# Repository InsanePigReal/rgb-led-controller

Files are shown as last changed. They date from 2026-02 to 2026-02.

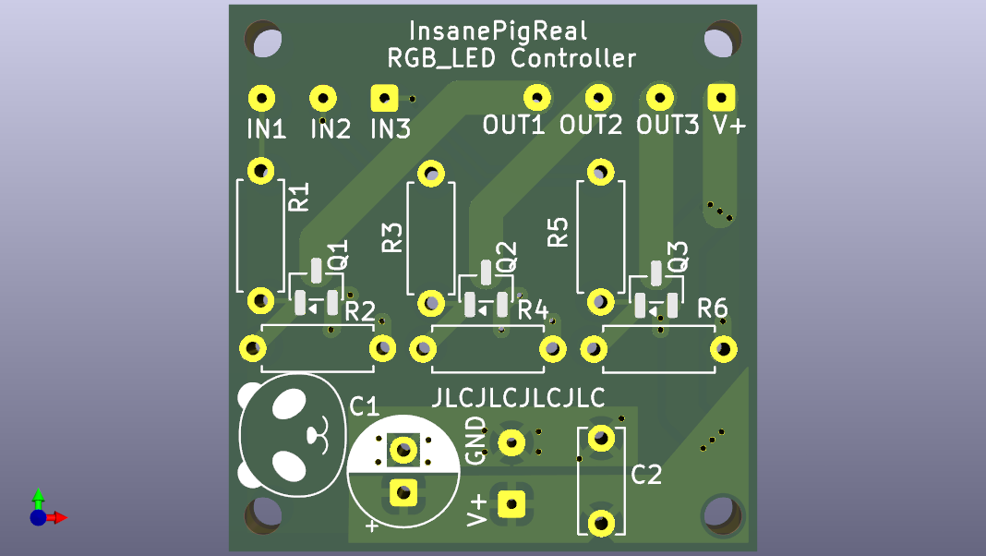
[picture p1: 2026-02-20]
assets/PCB_V5_Render.png

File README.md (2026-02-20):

# rgb-led-controller

# High-Current RGB LED Controller (24V)

A compact (30.99 mm* 32.07 mm = <1000mm^2), high efficiency PWM controller designed to drive 24V RGB LED strips using logic-level mosfets.

## Aims

- Design a small controller for an LED strip so that I can control LEDs in my house without a large, bulky controller -> the PCB must also be able to be easily mounted.
    - Previously, I controlled LEDs using components on a perfboard, however that was difficult to mount and organise with the amount of cables.
- The components must be cheap, as controllers can be purchased online for £10.
- Must functon at 24v, as the LEDs I have work at 24v.

## Specifications
- Input -> 24V - (IRLML6344 functions up to 30v)
- Control Logic -> 3.3v or 5v (micocontroller compatible) - (IRLML6344 functions up to 12v)
- Max Current -> 4A (per channel) - (limited by IRLML6344 Ip)
- Switching Frequency -> Tested up to 20kHz PWM

## Design Justification
- Trace widths:
    - Main power rails utilize 2mm traces. Based on IPC-2221 standards, this means that the traces can handle the max current of 4A.
    - Signal traces utilised 0.3mm traces, as they will not be carrying significant current (only control mosfet gates)

- Component selection:
    - IRLML6344
        - low gate threshold voltage - Vgs(th) - (0.5-1.1v), allowing it be driven with a 3.3v micocontroller signal without needing a gate driver.
        - Rated for Vds = 30v, providing a safe margin for 24v LEDs
        - Low on-resitance - Rds(on) = 29-37mΩ - minimises power dissipation, keeping the SOT-23 package cool when driving several amps of current
    - A mosfet was chosen instead of a relay due to its faster switching potential
        - This is useful for turning RGB LED strips on/off quickly -> for example, for decoration, where a mosfet will appear more seamless
        - Mosfets additonally consume less power, which is useful as the LED strips will be turned on for a large portion of the time (such as when the user is at work)
        - Mosfets are additionally more compact, which fufills one of the aims of the project (a compact RGB LED Controller
    - 100R Gate Resistor
        - Protects MCU GPIO by limiting peak current to (3.3V/100Ω=33mA)
    - 100K Pull-Down Resistor
        - Prevent floating GPIOs from causing the LEDs to flicker
        - 100K was chosen as a "weak" pull-down -> strong enough to bleed off charge but high enough to not wase significant power during operation
    - 100uF bulk electrolytic capacitor
        - Rated for 25V to ensure it can handle 24V load
        - Prevent voltage dips when switching
    - 100nF decoupling ceramic capacitor
        - Filter out high frequency noise from PWM switching -> ensures LED doesn't flicker

- Thermal managment: Added a large ground pour on the bottom layer, which will act as a heatsink for the SOT-23 mosfets.
    - SOT-23 Package can dissipate ≈ 1.25W
        - At 2A load, P = 2^2 * 0.037 = 0.148W -> design operates at a 8x safety factor regarding thermals
        - At 4A load, P = 4^2 * 0.037 = 0.592W -> design operates at a 2x safety factor regarding thermals

## Iteration and Improvements
PCB V1

1st version was not compact, meaning that it would not fit in tight spaces like I desired, as well as it being difficult to mount. Additionally, the capacitors were too far from the power supply, which would have lead to less stability and performance. Additionally, the length of the traces meant higher resistance and less signal integrity. Also, this design has no power input and no vias, so it would not have been functional.

PCB V2

2nd version improved on capacitor placement, as well as trace length and overall size. Additionally, it now included power input. However, some of the traces (such as the signal traces) were 90 degrees, which would be bad for manufacturability and signal integrity. Additionally, though I included vias, they would not be able to manufactured due to improper sizing.
Issues include the lack of moutning holes, as well as not using a ground pour and using a lot of ground traces, which created a higher impedance path. Additionally, a solid fill was used on the 24v plane, which would have made the PCB more difficult to hand solder.

PCB V5

Final version added mounting holes for the PCB, making it a more user-friendly design. Additionally, a ground pour was used instead of a the 'spider' of ground traces, and a thermal relief fill was used to make hand-soldering easier. Fixed the traces that were 90 degrees - now all traces are 45 degrees max. Furthermore, I changed the via diameter and hole size so that it fits with the chosen manufactuer's specifications. More vias were used than previously to ensure minimal voltage loss based on current.

# License
This project is licensed under the MIT License - see the LICENSE file for details

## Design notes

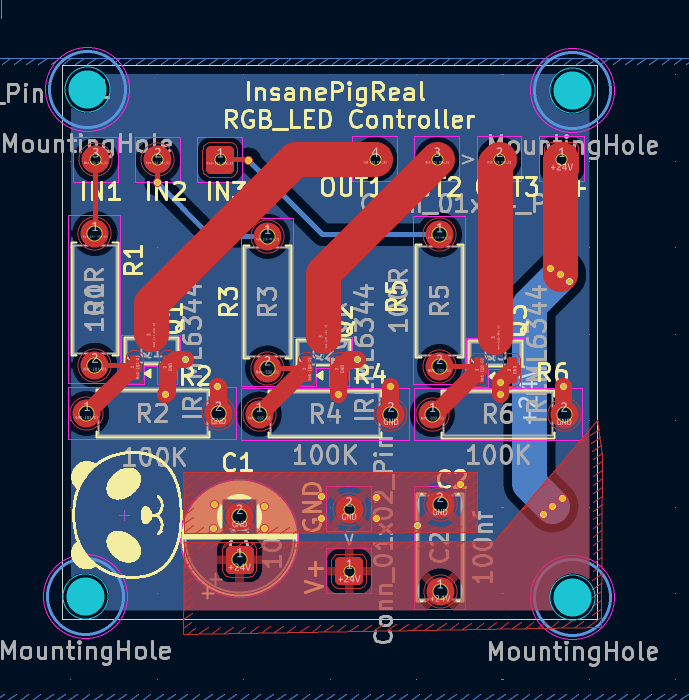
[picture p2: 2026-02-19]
assets/PCB V5.png

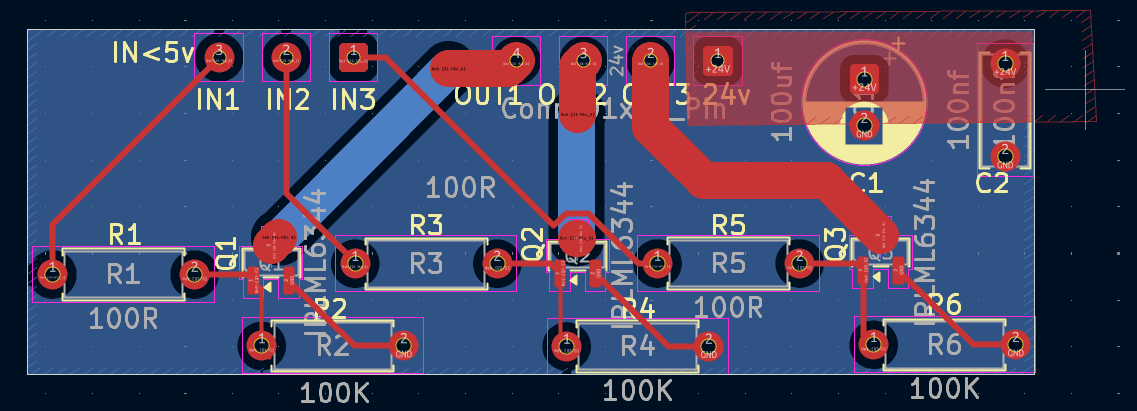
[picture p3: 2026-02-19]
assets/PCB V1.png

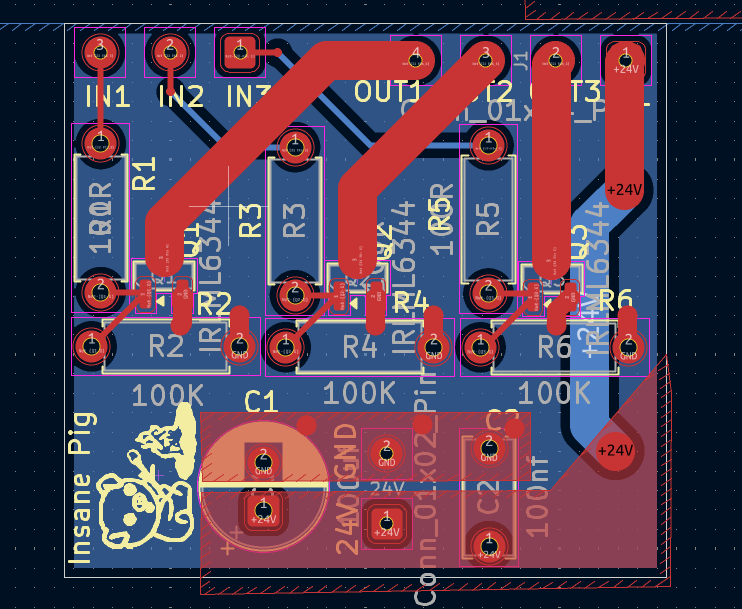
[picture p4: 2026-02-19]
assets/PCB V3.png

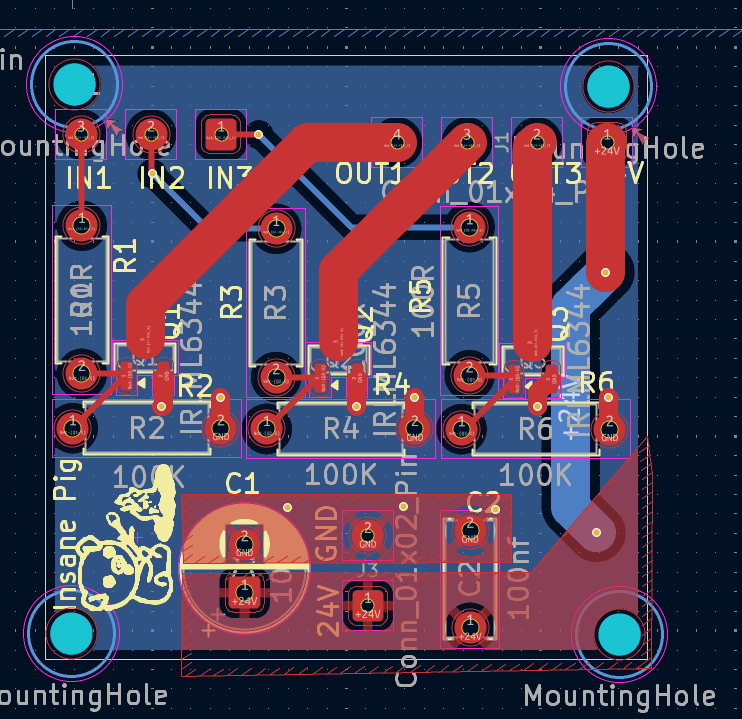
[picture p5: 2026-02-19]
assets/PCB V4.png

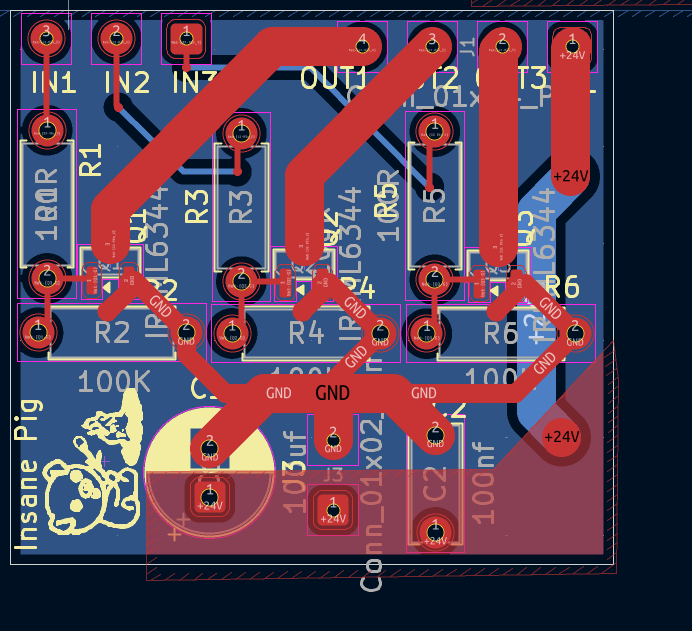
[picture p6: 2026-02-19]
assets/PCB V2.png

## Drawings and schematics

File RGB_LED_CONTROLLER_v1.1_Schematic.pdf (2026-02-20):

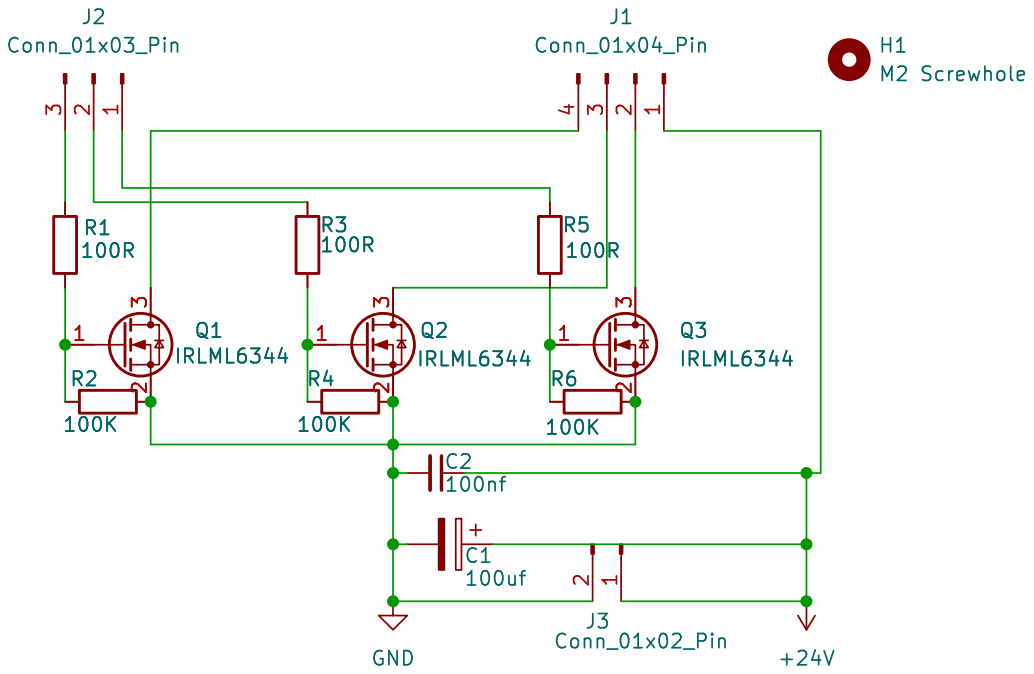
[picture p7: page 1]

Id: 1/1 Title: File: LedController1.kicad_sch Sheet: /

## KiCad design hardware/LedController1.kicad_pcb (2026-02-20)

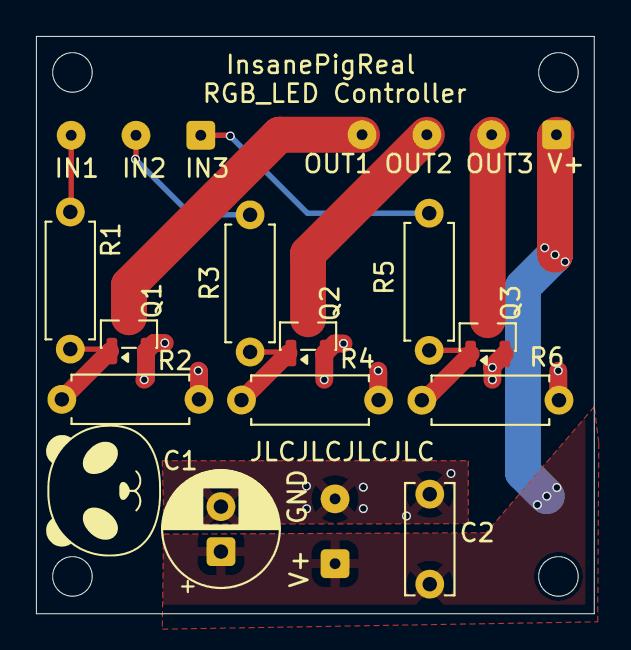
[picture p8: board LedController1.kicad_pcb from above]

Board: 2 copper layers, 31.0 x 32.1 mm, 18 parts (0 on the bottom side), 11 nets.

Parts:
C1: 100uf; CP_Radial_D6.3mm_P2.50mm
C2: 100nf; C_Disc_D6.0mm_W2.5mm_P5.00mm
H1, H1#2, H1#3, H1#4: MountingHole; MountingHole_2.2mm_M2
J2: Conn_01x03_Pin; SolderWire-0.1sqmm_1x03_P3.6mm_D0.4mm_OD1mm
Q1, Q2, Q3: IRLML6344; SOT-23
R1, R3, R5: 100R; R_Axial_DIN0207_L6.3mm_D2.5mm_P7.62mm_Horizontal
R2, R4, R6: 100K; R_Axial_DIN0207_L6.3mm_D2.5mm_P7.62mm_Horizontal
V+: Conn_01x02_Pin; SolderWire-0.1sqmm_1x02_P3.6mm_D0.4mm_OD1mm
V+#2: Conn_01x04_Pin; SolderWire-0.1sqmm_1x04_P3.6mm_D0.4mm_OD1mm

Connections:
+24V: C1.1, C2.1, V+.1, V+#2.1
GND: C1.2, C2.2, Q1.2 (S), Q2.2 (S), Q3.2 (S), R2.2, R4.2, R6.2, V+.2
unnamed: Q3.3 (D), V+#2.2
unnamed: Q2.3 (D), V+#2.3
unnamed: Q1.3 (D), V+#2.4
unnamed: J2.1, R5.1
unnamed: J2.2, R3.1
unnamed: J2.3, R1.1
unnamed: Q1.1 (G), R1.2, R2.1
unnamed: Q2.1 (G), R3.2, R4.1
unnamed: Q3.1 (G), R5.2, R6.1

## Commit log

2026-02-19 Added Kicad project files
    [LedController1.kicad_pcb, LedController1.kicad_sch]
2026-02-19 Added asset files for images of PCB and Schematic
2026-02-20 Added Kicad files
    [LedController1.kicad_pcb, LedController1.kicad_sch]
2026-02-20 Added Gerber files for manufacturing
2026-02-20 Uploaded render of the PCB
